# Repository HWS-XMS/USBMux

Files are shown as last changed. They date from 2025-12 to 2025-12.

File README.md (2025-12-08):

# USBMux

USB multiplexer for switching a USB device between two hosts, with VBUS power control.

## Hardware

- **MCU**: STM32F042F4P6 (USB CDC interface)
- **USB Mux**: FSUSB42MUX
- **VBUS Switch**: 2x TPS2051CDBV (with overcurrent/thermal protection)

KiCad design files in `hardware/`.

## Firmware

### Build

```bash
cd firmware
git submodule update --init --recursive
# Apply libopencm3 fix for STM32F042 USB bug
cd libopencm3 && patch -p1 < ../libopencm3-stm32f042-usb-fix.patch && cd ..
make -C libopencm3 TARGETS="stm32/f0" -j$(nproc)
make
```

**Note**: The patch fixes a critical bug in libopencm3's `st_usbfs_copy_from_pm()` function that causes data corruption when receiving odd-length USB packets on STM32F042. This bug has been reported to the libopencm3 project.

### Flash

```bash
make flash    # via ST-Link
make program  # via DFU mode
```

### Commands (USB CDC)

| Command | Description |
|---|---|
| `SEL 0` / `SEL 1` | Select host 0 or 1 |
| `SEL?` | Query selection |
| `OE 0` / `OE 1` | Disable/enable mux |
| `OE?` | Query mux enable |
| `EN0 0` / `EN0 1` | Disable/enable VBUS channel 0 |
| `EN0?` | Query VBUS 0 |
| `EN1 0` / `EN1 1` | Disable/enable VBUS channel 1 |
| `EN1?` | Query VBUS 1 |
| `FAULT?` | Query fault flags |
| `STATUS?` | Query all states |

Responses end with `\r\n`.

## Software

Python wrapper in `software/usbmux.py`.

```python
from usbmux import USBMux

with USBMux() as mux:      # auto-detects device
    mux.sel = 0            # select host 0
    mux.oe = True          # enable mux
    mux.en0 = True         # enable VBUS 0 (raises USBMuxFaultError on fault)
    print(mux.status)
```

Requires `pyserial`:
```bash
pip install pyserial
```

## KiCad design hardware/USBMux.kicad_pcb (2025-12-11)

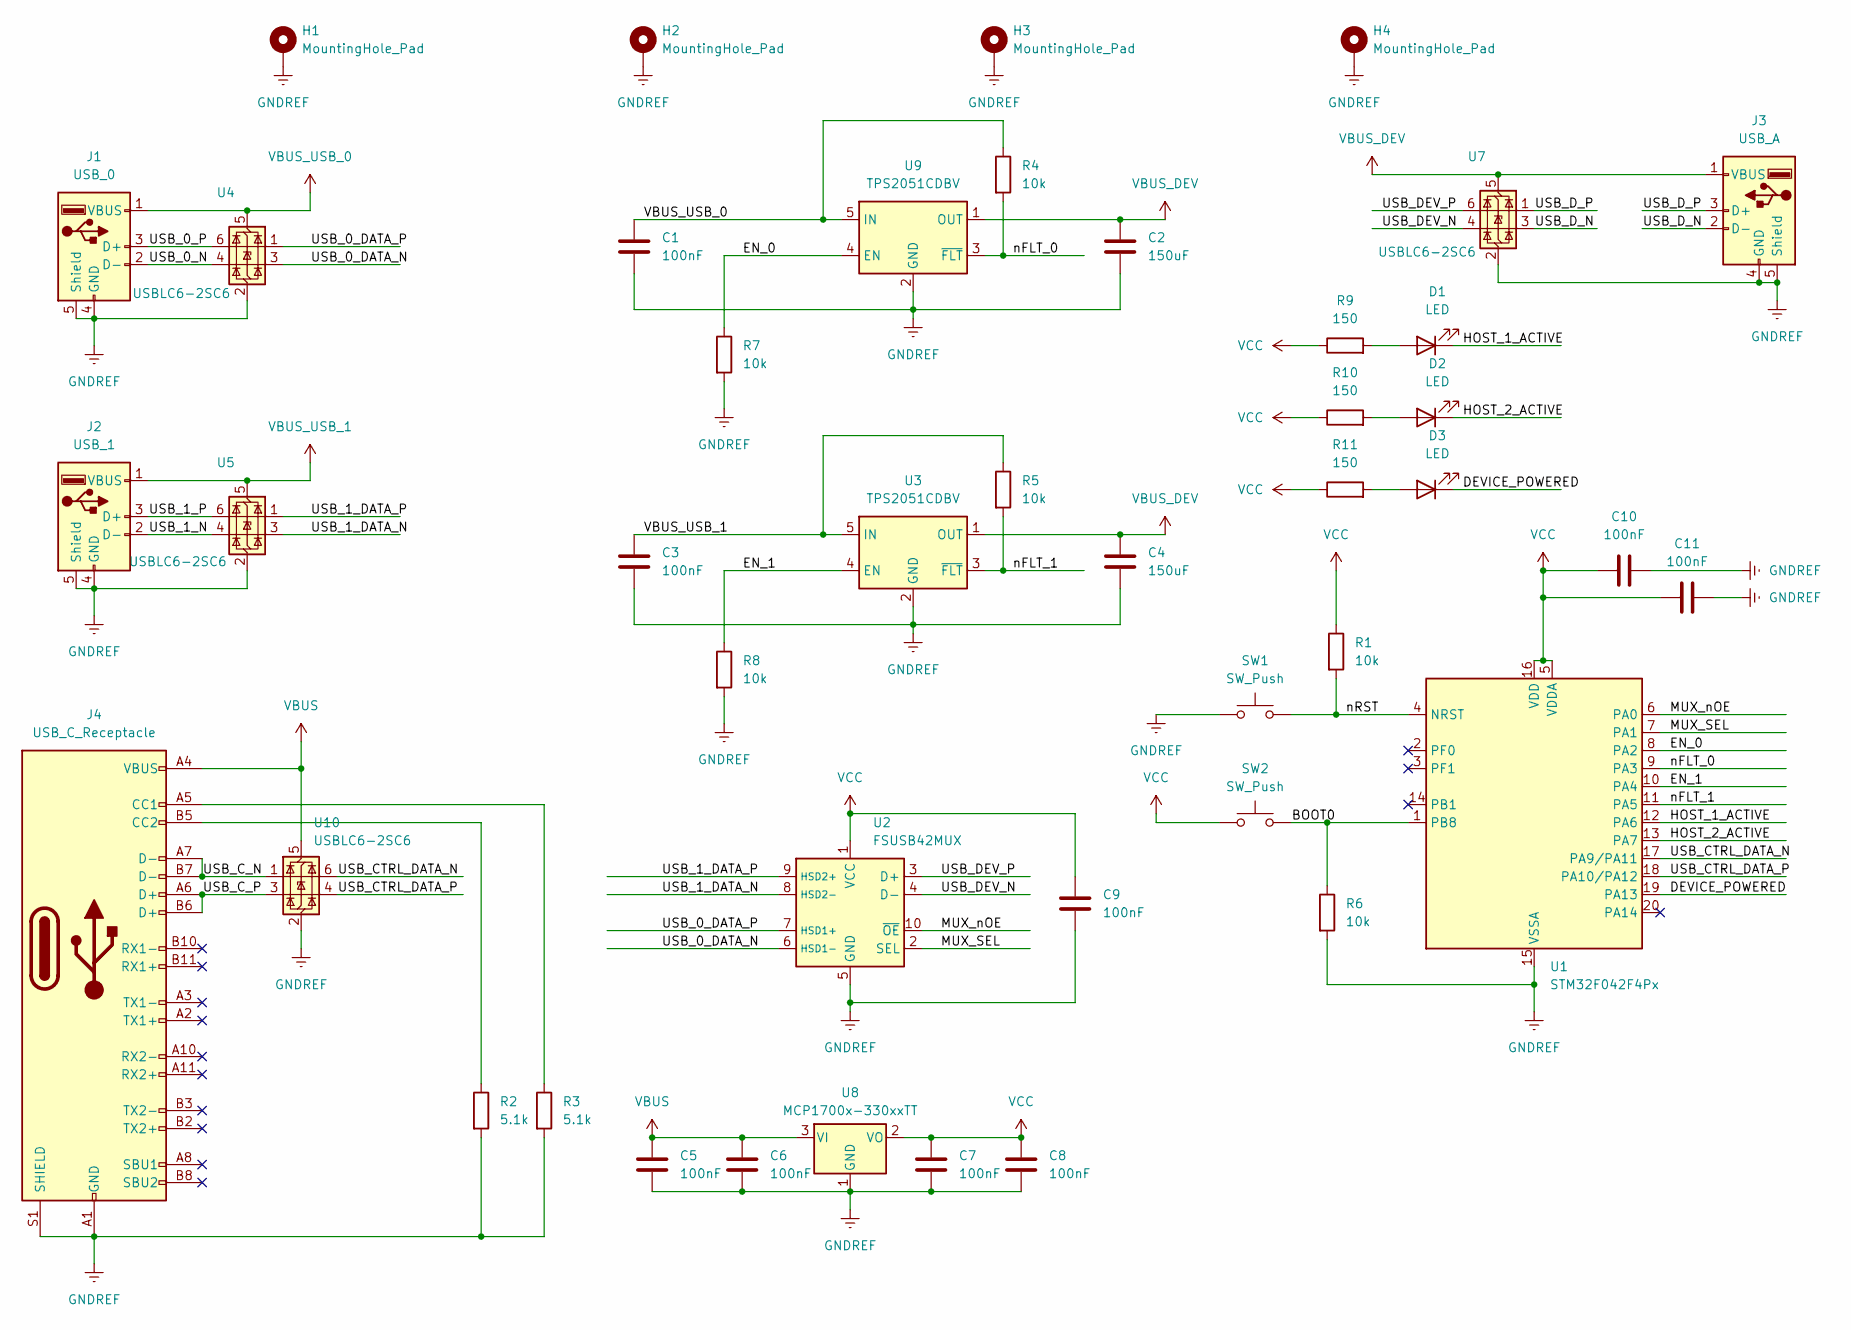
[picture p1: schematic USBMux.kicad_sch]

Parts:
C1, C3, C5, C6, C7, C8, C9, C10, C11: 100nF; C_0805_2012Metric_Pad1.18x1.45mm_HandSolder
C2, C4: 150uF; C_0805_2012Metric_Pad1.18x1.45mm_HandSolder
D1, D2, D3: LED; LED_0805_2012Metric_Pad1.15x1.40mm_HandSolder
H1, H2, H3, H4: MountingHole_Pad; MountingHole_3.2mm_M3_DIN965_Pad
J1: USB_0; USB_A_Receptacle_GCT_USB1046
J2: USB_1; USB_A_Receptacle_GCT_USB1046
J3: USB_A; USB_A_Receptacle_GCT_USB1046
J4: USB_C_Receptacle; USB_C_Receptacle_GCT_USB4085
R1, R4, R5, R6, R7, R8: 10k; R_0805_2012Metric_Pad1.20x1.40mm_HandSolder
R2, R3: 5.1k; R_0805_2012Metric_Pad1.20x1.40mm_HandSolder
R9, R10, R11: 150; R_0805_2012Metric_Pad1.20x1.40mm_HandSolder
SW1, SW2: SW_Push; SW_Push_1TS009xxxx-xxxx-xxxx_6x6x5mm
U1: STM32F042F4Px; TSSOP-20_4.4x6.5mm_P0.65mm
U2: FSUSB42MUX; MSOP-10_3x3mm_P0.5mm
U3, U9: TPS2051CDBV; SOT-23-5
U4, U5, U7, U10: USBLC6-2SC6; SOT-23-6
U8: MCP1700x-330xxTT; SOT-23

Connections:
/BOOT0: R6.1, SW2.2, U1.1 (PB8)
/DEVICE_POWERED: D3.1 (K), U1.19 (PA13)
/EN_0: R7.1, U1.8 (PA2), U9.4 (EN)
/EN_1: R8.1, U1.10 (PA4), U3.4 (EN)
/HOST_1_ACTIVE: D1.1 (K), U1.12 (PA6)
/HOST_2_ACTIVE: D2.1 (K), U1.13 (PA7)
/MUX_SEL: U1.7 (PA1), U2.2 (SEL)
/MUX_nOE: U1.6 (PA0), U2.10 (~OE)
/USB_0_DATA_N: U2.6 (HSD1-), U4.3 (I/O2)
/USB_0_DATA_P: U2.7 (HSD1+), U4.1 (I/O1)
/USB_0_N: J1.2 (D-), U4.4 (I/O2)
/USB_0_P: J1.3 (D+), U4.6 (I/O1)
/USB_1_DATA_N: U2.8 (HSD2-), U5.3 (I/O2)
/USB_1_DATA_P: U2.9 (HSD2+), U5.1 (I/O1)
/USB_1_N: J2.2 (D-), U5.4 (I/O2)
/USB_1_P: J2.3 (D+), U5.6 (I/O1)
/USB_CTRL_DATA_N: U1.17 (PA9/PA11), U10.6 (I/O1)
/USB_CTRL_DATA_P: U1.18 (PA10/PA12), U10.4 (I/O2)
/USB_C_N: J4.A7 (D-), J4.B7 (D-), U10.1 (I/O1)
/USB_C_P: J4.A6 (D+), J4.B6 (D+), U10.3 (I/O2)
/USB_DEV_N: U2.4 (D-), U7.4 (I/O2)
/USB_DEV_P: U2.3 (D+), U7.6 (I/O1)
/USB_D_N: J3.2 (D-), U7.3 (I/O2)
/USB_D_P: J3.3 (D+), U7.1 (I/O1)
/nFLT_0: R4.2, U1.9 (PA3), U9.3 (~FLT)
/nFLT_1: R5.2, U1.11 (PA5), U3.3 (~FLT)
/nRST: R1.2, SW1.2, U1.4 (NRST)
GNDREF: C1.2, C2.2, C3.2, C4.2, C5.2, C6.2, C7.2, C8.2, C9.2, C10.1, C11.1, H1.1, H2.1, H3.1, H4.1, J1.4 (GND), J1.5 (Shield), J2.4 (GND), J2.5 (Shield), J3.4 (GND), J3.5 (Shield), J4.A1 (GND), J4.A12 (GND), J4.B1 (GND), J4.B12 (GND), J4.S1 (SHIELD), R2.2, R3.2, R6.2, R7.2, R8.2, SW1.1, U1.15 (VSSA), U2.5 (GND), U3.2 (GND), U4.2 (GND), U5.2 (GND), U7.2 (GND), U8.1 (GND), U9.2 (GND), U10.2 (GND)
unnamed: D1.2 (A), R9.2
unnamed: D2.2 (A), R10.2
unnamed: D3.2 (A), R11.2
unnamed: J4.A5 (CC1), R3.1
unnamed: J4.B5 (CC2), R2.1
VBUS: C5.1, C6.1, J4.A4 (VBUS), J4.A9 (VBUS), J4.B4 (VBUS), J4.B9 (VBUS), U8.3 (VI), U10.5 (VBUS)
VBUS_DEV: C2.1, C4.1, J3.1 (VBUS), U3.1 (OUT), U7.5 (VBUS), U9.1 (OUT)
VBUS_USB_0: C1.1, J1.1 (VBUS), R4.1, U4.5 (VBUS), U9.5 (IN)
VBUS_USB_1: C3.1, J2.1 (VBUS), R5.1, U3.5 (IN), U5.5 (VBUS)
VCC: C7.1, C8.1, C9.1, C10.2, C11.2, R1.1, R9.1, R10.1, R11.1, SW2.1, U1.5 (VDDA), U1.16 (VDD), U2.1 (VCC), U8.2 (VO)

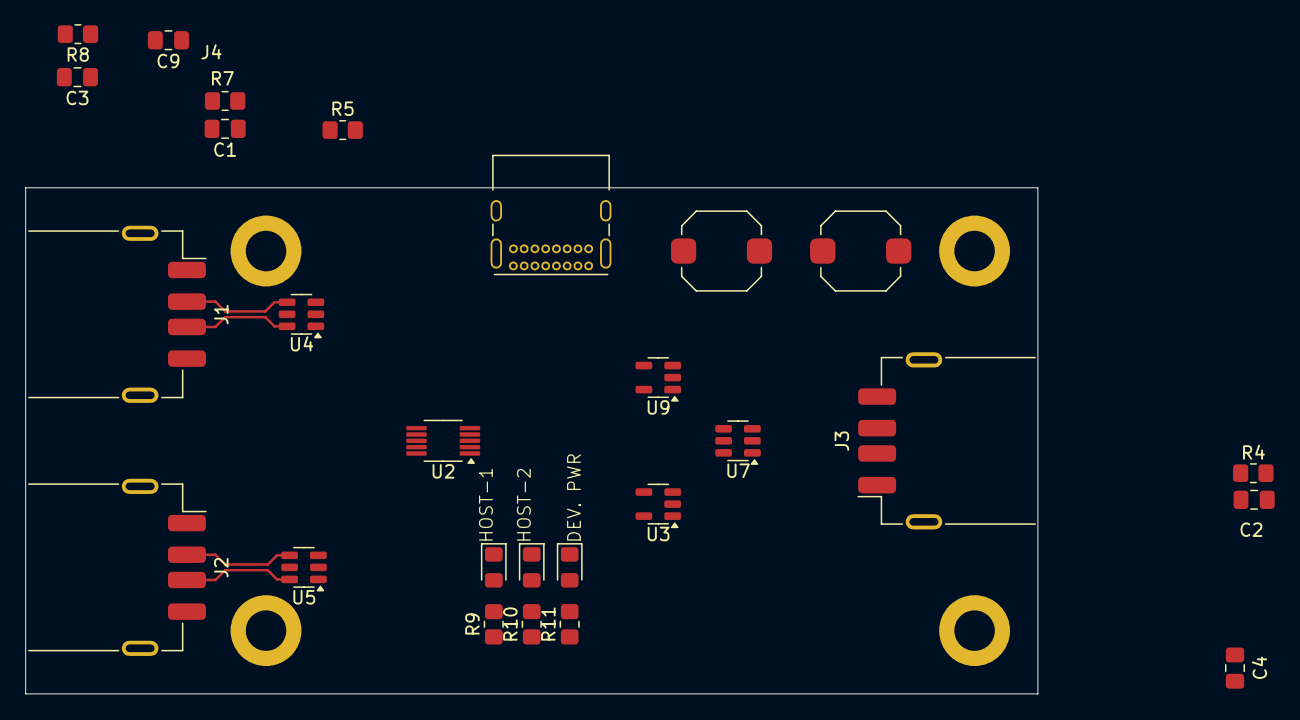
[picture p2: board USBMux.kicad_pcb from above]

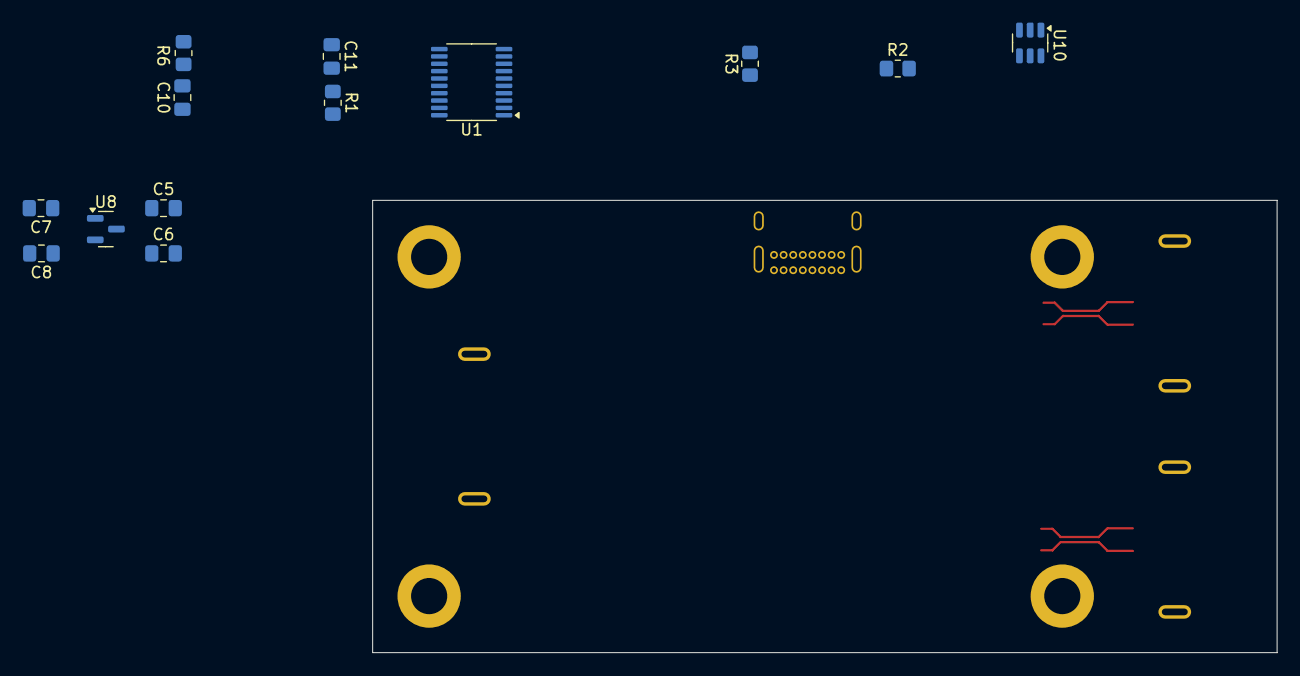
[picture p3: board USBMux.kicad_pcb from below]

Board: 4 copper layers, 80.0 x 40.0 mm, 44 parts (13 on the bottom side), 38 nets.

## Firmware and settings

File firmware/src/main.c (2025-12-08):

#include <libopencm3/stm32/rcc.h>
#include <libopencm3/stm32/flash.h>
#include <stddef.h>
#include "gpio.h"
#include "usb_cdc.h"
#include "commands.h"

static char cmd_buf[64];
static size_t cmd_len = 0;

static void clock_setup(void)
{
    /* Enable HSI48 for USB */
    rcc_osc_on(RCC_HSI48);
    rcc_wait_for_osc_ready(RCC_HSI48);

    /* Set HSI48 as system clock */
    rcc_set_sysclk_source(RCC_HSI48);
    while ((RCC_CFGR & RCC_CFGR_SWS) != RCC_CFGR_SWS_HSI48)
        ;

    /* Update the SystemCoreClock variable */
    rcc_ahb_frequency = 48000000;
    rcc_apb1_frequency = 48000000;
}

static void process_incoming_data(void)
{
    char buf[64];
    size_t len = usb_cdc_read(buf, sizeof(buf));

    for (size_t i = 0; i < len; i++) {
        char c = buf[i];

        if (c == '\r' || c == '\n') {
            if (cmd_len > 0) {
                cmd_buf[cmd_len] = '\0';
                commands_process(cmd_buf, cmd_len);
                cmd_len = 0;
            }
        } else if (cmd_len < sizeof(cmd_buf) - 1) {
            cmd_buf[cmd_len++] = c;
        }
    }
}

int main(void)
{
    clock_setup();
    gpio_init();
    usb_cdc_init();

    while (1) {
        usb_cdc_poll();
        process_incoming_data();
    }

    return 0;
}

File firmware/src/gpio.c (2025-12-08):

#include "gpio.h"
#include <libopencm3/stm32/rcc.h>
#include <libopencm3/stm32/gpio.h>

#define MUX_NOE_PIN   GPIO0
#define MUX_SEL_PIN   GPIO1
#define EN0_PIN       GPIO2
#define NFAULT0_PIN   GPIO3
#define EN1_PIN       GPIO4
#define NFAULT1_PIN   GPIO5

void gpio_init(void)
{
    rcc_periph_clock_enable(RCC_GPIOA);

    /* Outputs: MUX_nOE, MUX_SEL, EN_0, EN_1 */
    gpio_mode_setup(GPIOA, GPIO_MODE_OUTPUT, GPIO_PUPD_NONE,
                    MUX_NOE_PIN | MUX_SEL_PIN | EN0_PIN | EN1_PIN);

    /* Inputs: nFAULT_0, nFAULT_1 (active low, external pull-up to VBUS_DEV) */
    gpio_mode_setup(GPIOA, GPIO_MODE_INPUT, GPIO_PUPD_NONE,
                    NFAULT0_PIN | NFAULT1_PIN);

    /* Default state: mux disabled, both VBUS channels off */
    gpio_set(GPIOA, MUX_NOE_PIN);    /* nOE high = mux disabled */
    gpio_clear(GPIOA, MUX_SEL_PIN);  /* SEL = 0 */
    gpio_clear(GPIOA, EN0_PIN);      /* VBUS0 off */
    gpio_clear(GPIOA, EN1_PIN);      /* VBUS1 off */
}

void gpio_set_mux_sel(bool sel)
{
    if (sel)
        gpio_set(GPIOA, MUX_SEL_PIN);
    else
        gpio_clear(GPIOA, MUX_SEL_PIN);
}

bool gpio_get_mux_sel(void)
{
    return (GPIO_ODR(GPIOA) & MUX_SEL_PIN) != 0;
}

void gpio_set_mux_oe(bool enable)
{
    /* nOE is active low: enable=true -> pin low */
    if (enable)
        gpio_clear(GPIOA, MUX_NOE_PIN);
    else
        gpio_set(GPIOA, MUX_NOE_PIN);
}

bool gpio_get_mux_oe(void)
{
    /* Return true if mux is enabled (nOE pin is low) */
    return (GPIO_ODR(GPIOA) & MUX_NOE_PIN) == 0;
}

void gpio_set_en0(bool enable)
{
    if (enable)
        gpio_set(GPIOA, EN0_PIN);
    else
        gpio_clear(GPIOA, EN0_PIN);
}

bool gpio_get_en0(void)
{
    return (GPIO_ODR(GPIOA) & EN0_PIN) != 0;
}

void gpio_set_en1(bool enable)
{
    if (enable)
        gpio_set(GPIOA, EN1_PIN);
    else
        gpio_clear(GPIOA, EN1_PIN);
}

bool gpio_get_en1(void)
{
    return (GPIO_ODR(GPIOA) & EN1_PIN) != 0;
}

bool gpio_get_fault0(void)
{
    /* nFAULT is active low: return true if fault present */
    return (gpio_get(GPIOA, NFAULT0_PIN) == 0);
}

bool gpio_get_fault1(void)
{
    return (gpio_get(GPIOA, NFAULT1_PIN) == 0);
}

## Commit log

2025-12-08 Testing FW on actual HW; fixing libopencm3 bug in STM USB;
    [main.c]
2025-12-08 Creatning a proper package and assigning custom PID/VID
2025-12-11 Update PCB, fix bug in BOOT0
    [USBMux.kicad_pcb, USBMux.kicad_sch]
